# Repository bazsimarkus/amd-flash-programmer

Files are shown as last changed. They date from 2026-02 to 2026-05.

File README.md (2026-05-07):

# amd-flash-programmer
A simple Arduino-based flash memory programmer for AM29F010 and AM29F040B series flash chips.

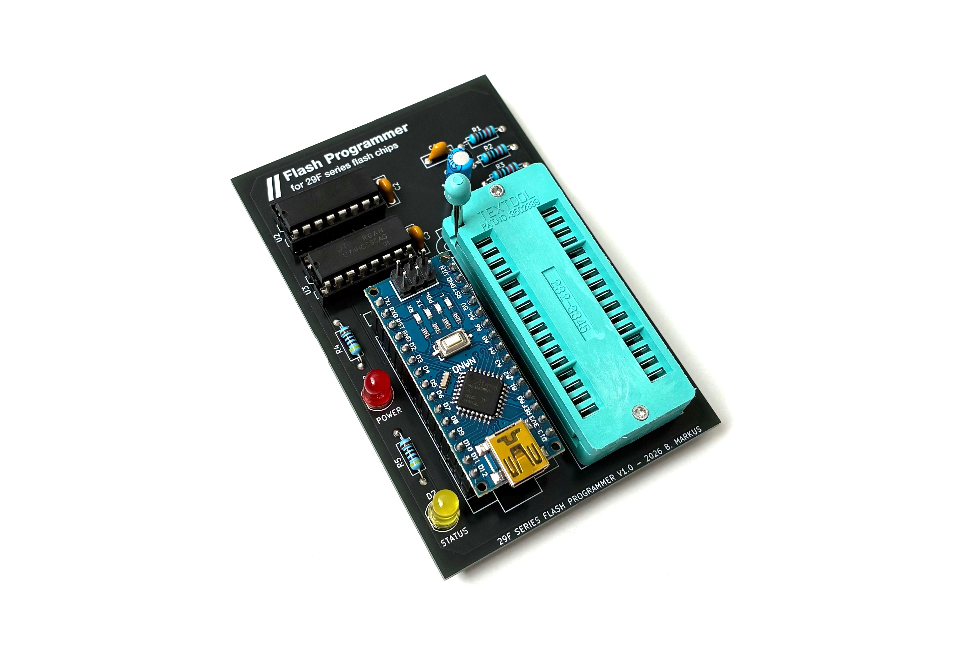
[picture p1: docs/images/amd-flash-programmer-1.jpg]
AMD Flash Programmer Board


---

## Table of Contents

- [Overview](#overview)
- [Features](#features)
- [Hardware](#hardware)
  - [Schematic](#schematic)
  - [How It Works](#how-it-works)
  - [Bill of Materials](#bill-of-materials)
  - [Pin Mapping](#pin-mapping)
  - [Supported Chips](#supported-chips)
  - [PCB](#pcb)
- [Firmware](#firmware)
  - [Architecture](#architecture)
  - [Serial Protocol](#serial-protocol)
  - [Uploading the Firmware](#uploading-the-firmware)
- [Client Software](#client-software)
  - [Installation](#installation)
  - [Usage](#usage)
- [How to Use](#how-to-use)
  - [Connect](#connect)
  - [Read Chip ID](#read-chip-id)
  - [Read Memory](#read-memory)
  - [Erase Chip](#erase-chip)
  - [Write File](#write-file)
  - [Verify](#verify)
- [Performance](#performance)
- [Known Limitations & Future Ideas](#known-limitations--future-ideas)
- [Personal Notes](#personal-notes)
- [Inspirations & Credits](#inspirations--credits)

---

## Overview

I always needed a way to program AM29F040B flash chips without spending money on an expensive universal programmer. My [ATmega32-based MOD tracker player](https://github.com/bazsimarkus/avr-mod-player) uses this chip to store `.mod` tracker files, and to be able to write new music onto the player I decided to design a dedicated programmer board. These chips were also used in Game Boy Color cartridges, among other things, so there is a retro community out there that might find this useful too.

My main inspiration was [TommyPROM](https://github.com/TomNisbet/TommyPROM), but TommyPROM is a general-purpose EEPROM programmer and doesn't directly support the AMD 29F-series flash command sequences. The AM29F010 and AM29F040B use software-controlled erase and programming cycles with specific unlock addresses - you can't just write to them like a parallel EEPROM. So I designed my own board, wrote the Arduino firmware from scratch, and also created a Python GUI client to make the whole process beginner-friendly.

The result is a simple, easy-to-build board that does exactly what I need: read, write, erase, and verify AM29F-series flash chips over USB.

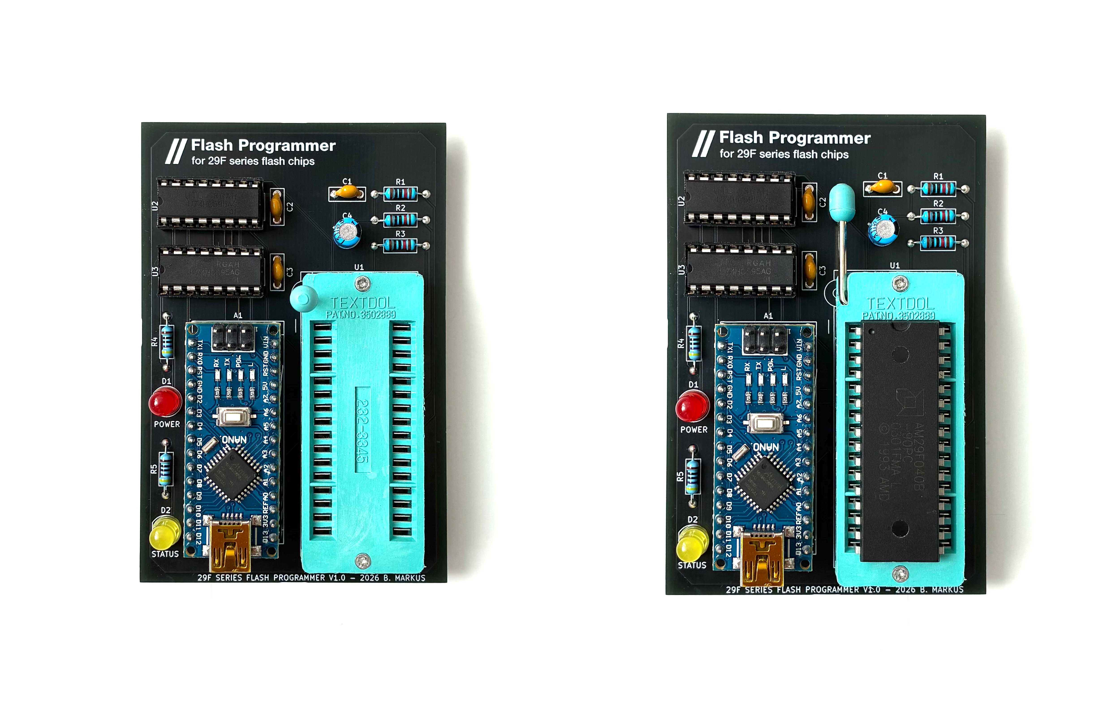
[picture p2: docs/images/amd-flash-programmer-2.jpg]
AMD Flash Programmer Board Double Top View


---

## Features

- **Read** - full chip or custom hex address range, displayed in a live hex viewer
- **Write** - binary files to flash with byte-by-byte handshake protocol
- **Erase** - full chip erase with proper DQ7 data polling
- **Verify** - automatic post-write verification or manual verify against any file
- **Chip ID** - reads manufacturer and device ID via autoselect mode
- **Hex Viewer** - colour-coded hex dump with ASCII column in the GUI
- **Event Log** - timestamped log of all operations, exportable to file
- **COM port auto-detection** - scans and lists available serial ports
- Supports **AM29F010** (128 KB) and **AM29F040B** (512 KB)
- Beginner-friendly - easy to solder, easy to flash, easy to use
- All through-hole components - no SMD soldering required
- Powered directly from USB via the Arduino Nano

---

## Hardware

### Schematic

<p align="center">
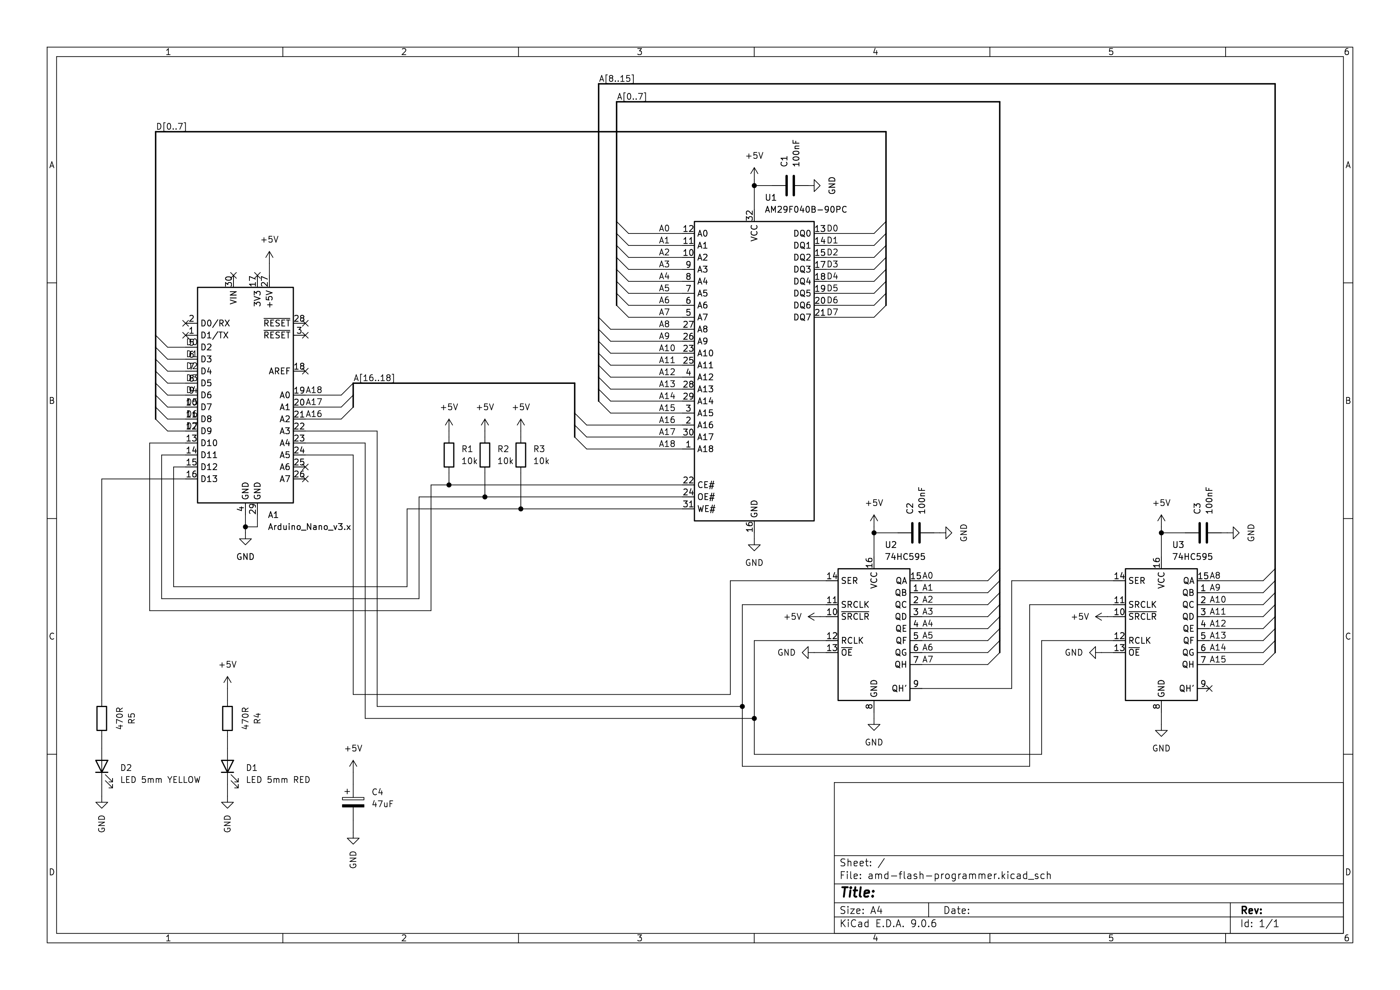
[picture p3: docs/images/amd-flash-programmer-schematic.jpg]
Flash Programmer Schematic
  
</p>

The full KiCad project including schematic, PCB layout, and netlist is available in the `schematic/` folder.

---

### How It Works

The circuit is straightforward. There are only a few building blocks, and each has a clear job.

**Arduino Nano (A1)** - This is the brain of the board. It handles USB serial communication with the PC at 115200 baud, generates the timing for the shift registers, drives the flash chip's control signals (CE#, OE#, WE#), and reads/writes the 8-bit data bus. It is powered directly from the USB cable, and provides 5V to the rest of the circuit from its onboard regulator.

**74HC595 Shift Registers (U2, U3)** - The AM29F040B has 19 address lines (A0-A18), which is far more than what the Arduino Nano has available as spare GPIO. The solution is to use two 74HC595 shift registers daisy-chained together. These are 8-bit serial-in, parallel-out shift registers. The Arduino sends 16 bits of address data serially using just three control lines (serial data on A5, shift clock on A3, and latch clock on A4), and the two shift registers present all 16 bits simultaneously on their parallel outputs. U2 provides address lines A0-A7 (low byte), and its serial overflow output (QH') feeds into U3 which provides A8-A15 (high byte). The remaining three address lines (A16, A17, A18) are driven directly from the Nano's analog pins A0, A1, and A2 - there is no need to shift those since there are only three of them and the Nano has enough free pins.

**Flash Chip Socket (U1)** - A 32-pin ZIF (Zero Insertion Force) Textool socket. ZIF sockets have a lever that opens and closes the contacts, so you can insert and remove DIP chips without bending any pins. This is important because if you are regularly swapping flash chips in and out, a standard friction-fit DIP socket will eventually damage the pins or wear out. The ZIF socket is the most expensive component on the board, but it is worth it.

**Data Bus (D2-D9)** - The flash chip's 8-bit data bus (DQ0-DQ7) connects directly to Arduino Nano pins D2 through D9. These pins are mapped to PORTD bits 2-7 and PORTB bits 0-1 in the firmware. During a read, the Arduino sets these as inputs and reads the parallel data from the flash. During a write, it sets them as outputs and drives the data to be programmed.

**Control Signals (D10, D11, D12)** - Three active-low control signals go from the Arduino to the flash chip:
- **CE#** (Chip Enable) on D10 - must be low for the chip to respond to any bus cycle
- **OE#** (Output Enable) on D11 - drives the chip's data outputs onto the bus during a read
- **WE#** (Write Enable) on D12 - latches data into the chip during a write or command cycle

All three have 10kΩ pull-up resistors (R1, R2, R3) to +5V. This is a safety measure: during Arduino power-up, reset, or bootloader execution, the GPIO pins are momentarily tri-stated (floating). Without the pull-ups, the flash chip might interpret random noise on CE#, OE#, and WE# as valid bus cycles and get confused or, in a worst case, accidentally erase data. The pull-ups ensure all control signals default to their inactive (high) state until the firmware explicitly takes control.

**LEDs (D1, D2)** - A red LED for power indication (always on when USB is connected) and a yellow LED for status (blinks during operations). Each LED has a 470Ω series resistor (R4 for the power LED, R5 for the status LED) to limit the current to a safe value. The status LED is connected to D13, which is the Arduino's built-in LED pin.

**Decoupling Capacitors (C1, C2, C3, C4)** - Three 100nF ceramic capacitors are placed near the power supply pins of U1 (flash chip), U2, and U3 (shift registers). These are standard bypass capacitors that filter out high-frequency noise on the power supply lines. Without them, the rapid switching of the digital logic creates voltage spikes that can cause unreliable operation, especially on the flash chip which has tight timing requirements. C4 is a 47µF electrolytic capacitor providing bulk energy storage for the entire board, smoothing out any supply droop when the flash chip draws current during erase or programming operations.

---

### Bill of Materials

| Reference | Qty | Value / Part | Description |
|---|-----|---|---|
| A1 | 1 | Arduino Nano v3.x | Main microcontroller module (ATmega328P) |
| U1 | 1 | 32-pin ZIF Socket (Textool) | Zero-insertion-force socket for flash chip |
| U2 | 1 | 74HC595 (DIP-16) | 8-bit shift register - address lines A0-A7 |
| U3 | 1 | 74HC595 (DIP-16) | 8-bit shift register - address lines A8-A15 |
| D1 | 1 | LED 5mm RED | Power indicator |
| D2 | 1 | LED 5mm YELLOW | Status indicator (directly controlled via D13) |
| R1, R2 | 2 | 10kΩ | Pull-up resistors for CE# and OE# |
| R3 | 1 | 10kΩ | Pull-up resistor for WE# |
| R4 | 1 | 470Ω | Current limiting resistor for power LED |
| R5 | 1 | 470Ω | Current limiting resistor for status LED |
| C1, C2, C3 | 3 | 100nF ceramic | Decoupling capacitors (one per IC) |
| C4 | 1 | 47µF electrolytic | Bulk power filtering |

All components are through-hole and readily available from any electronics supplier. The total component cost (excluding the Arduino Nano and ZIF socket) is under 2 EUR.

---

### Pin Mapping

The Arduino Nano's pins are allocated as follows:

| Arduino Pin | Port | Function |
|---|---|---|
| D2-D9 | PORTD[2:7], PORTB[0:1] | Flash data bus DQ0-DQ7 |
| D10 | PORTB2 | Flash CE# (active low) |
| D11 | PORTB3 | Flash OE# (active low) |
| D12 | PORTB4 | Flash WE# (active low) |
| D13 | PORTB5 | Status LED |
| A0 | PORTC0 | Flash A18 (directly driven) |
| A1 | PORTC1 | Flash A17 (directly driven) |
| A2 | PORTC2 | Flash A16 (directly driven) |
| A3 | PORTC3 | Shift register SRCLK (clock) |
| A4 | PORTC4 | Shift register RCLK (latch) |
| A5 | PORTC5 | Shift register SER (serial data) |

The two 74HC595 shift registers are daisy-chained: U2 provides A0-A7 and its serial overflow (QH') feeds into U3 which provides A8-A15. This gives 16 address bits via SPI-like shifting, plus 3 bits driven directly, totalling 19 address lines - enough for 512 KB.

---

### Supported Chips

| Chip | Size | Unlock 1 | Unlock 2 | Mfr ID | Dev ID |
|---|---|---|---|---|---|
| AM29F010 | 128 KB (131,072 bytes) | 0x5555 | 0x2AAA | 0x01 | 0x20 |
| AM29F040B | 512 KB (524,288 bytes) | 0x0555 | 0x02AA | 0x01 | 0xA4 |

Note that the two chips use different unlock address sequences - the firmware handles this automatically based on the selected chip type.

---

### PCB

The PCB is revision **v1.0**, designed in KiCad 9.0.6. It is a single-sided through-hole board manufactured with black soldermask and white silkscreen. The board was manufactured by JLCPCB. All components are through-hole for ease of hand assembly - this is a beginner-friendly build that anyone with basic soldering skills can complete in under an hour.

The full KiCad project including schematic, PCB layout, and Gerber files is in the `schematic/` folder.

---

## Firmware

### Architecture

The firmware (`amd-flash-programmer.ino`) is written in C/C++ using the Arduino framework, but with direct port manipulation for speed. It runs at 115200 baud and implements a simple text-based command protocol over serial.

Key design decisions:

- **Direct port manipulation** - the data bus and control signals are manipulated via `PORTB`, `PORTD`, and `PORTC` registers rather than `digitalWrite()`, which would be too slow for the programming timing requirements.
- **Byte-by-byte handshake for writes** - the Arduino Nano has only a 64-byte UART receive buffer. At 115200 baud, bytes arrive at ~11 KB/s, but programming a byte to flash takes up to 200µs. A naive burst approach would overflow the buffer. Instead, the firmware programs one byte, sends a single `'K'` ACK character, and the host waits for that ACK before sending the next byte. This is slower (~0.5 KB/s) but 100% reliable.
- **DQ7 data polling** - both byte programming and chip erase use the AMD-standard DQ7 polling algorithm to detect completion, with DQ5 error checking as a fallback.
- **70-second erase timeout** - the AM29F040B datasheet specifies a maximum chip erase time of ~64 seconds, so the firmware allows up to 70 seconds before declaring a timeout.

---

### Serial Protocol

All commands are ASCII, terminated with `\n`. The Arduino responds with ASCII status lines.

| Command | Description | Response |
|---|---|---|
| `?` | Status query | `STATUS:<chip_name> SIZE:<bytes>` |
| `C<idx>` | Select chip (0=AM29F010, 1=AM29F040B) | `CHIP_OK:<name>` or `CHIP_ERR:...` |
| `I` | Read chip ID (autoselect mode) | `MFR:<hex> DEV:<hex>` |
| `R <start_hex> <end_hex>` | Read address range | `RSTART <count>` + raw bytes + `REND` |
| `E` | Full chip erase | `ERASE_START` → `ERASE_OK` or `ERASE_FAIL` |
| `W <size_dec>` | Write `<size>` bytes | `WREADY` → (byte-by-byte with `K` ACKs) → `WDONE:<n>` |

---

### Uploading the Firmware

1. Open `amd-flash-programmer.ino` in the Arduino IDE
2. Select **Board:** `Arduino Nano`
3. Select **Processor:** `ATmega328P` (or `ATmega328P (Old Bootloader)` depending on your board)
4. Select the correct COM port
5. Click **Upload**

No external libraries are required - the firmware uses only standard AVR headers and the Arduino Serial library.

---

## Client Software

The Python GUI client (`amd-flash-programmer-client.py`) provides a complete graphical interface for interacting with the programmer board.

<p align="center">
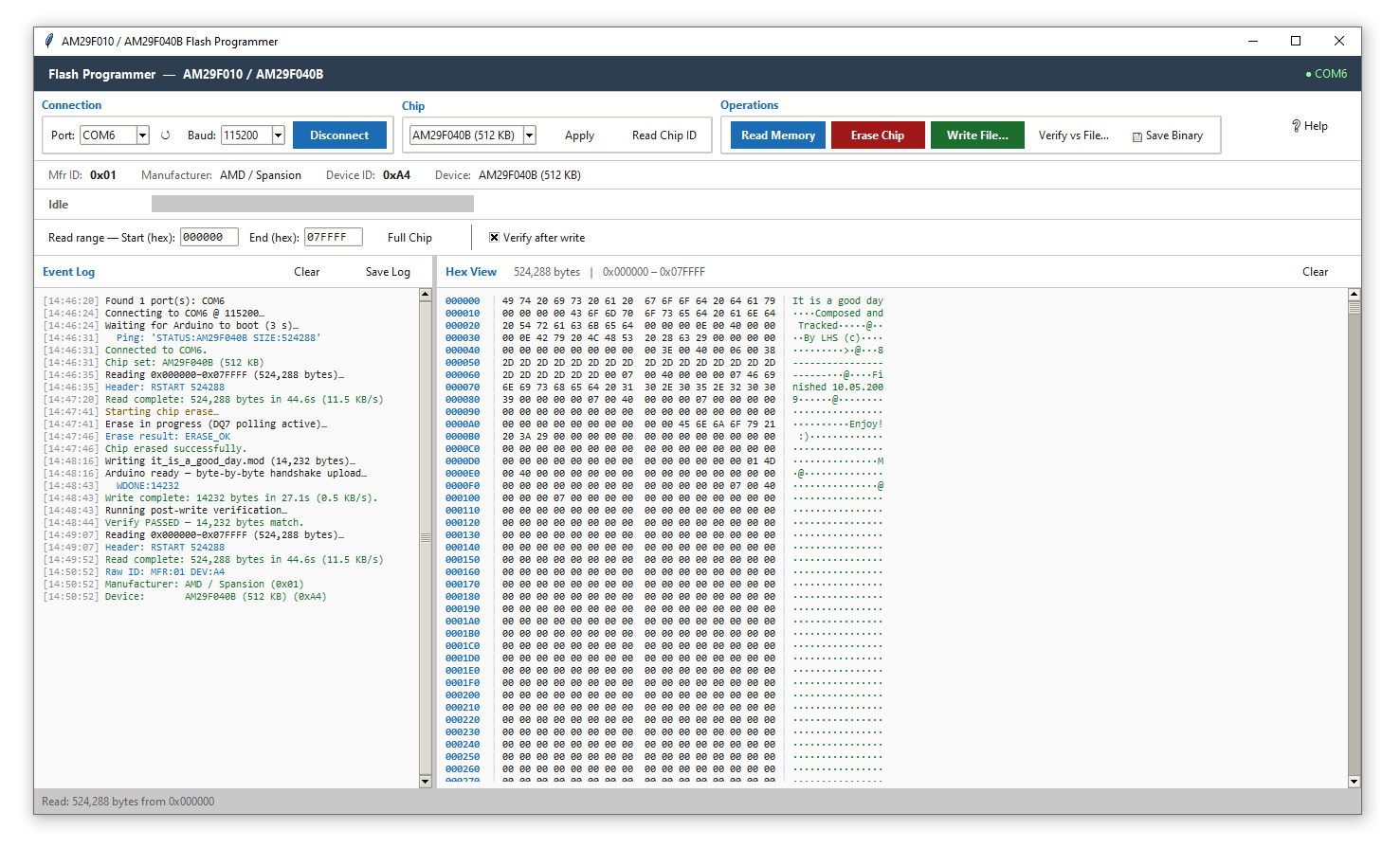
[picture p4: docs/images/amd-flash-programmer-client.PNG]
Flash Programmer Client Software
  
</p>

### Installation

Requires Python 3.x with `pyserial`:

```bash
pip install pyserial
python amd-flash-programmer-client.py
```

The client is built entirely with `tkinter` (included with Python) and `pyserial` - no other dependencies.

---

### Usage

The GUI is split into several sections:

- **Connection panel** - COM port selection, baud rate, connect/disconnect
- **Chip panel** - chip type selection (AM29F010 / AM29F040B), Apply, Read Chip ID
- **Operations panel** - Read Memory, Erase Chip, Write File, Verify vs File, Save Binary
- **Progress bar** - shows real-time progress with speed and ETA
- **Read range** - configurable start/end addresses (hex), Full Chip button
- **Event Log** (left panel) - timestamped log of all events, saveable to file
- **Hex View** (right panel) - colour-coded hex dump with address, hex bytes, and ASCII columns

The client includes a built-in chip database with known manufacturer IDs (AMD/Spansion, Fujitsu, Atmel, ST Micro, SST, Macronix, Winbond, etc.) and will display human-readable names when a chip ID is read.

---

## How to Use

### Connect

1. Insert the flash chip into the ZIF socket - **pin 1 goes to the top** (lever side)
2. Close the ZIF lever to lock the chip in place
3. Connect the Arduino Nano to your computer via USB
4. Launch the Python client
5. Select the correct COM port from the dropdown and click **Connect**
6. The client will reset the Arduino and wait for it to boot (~3 seconds)

### Read Chip ID

Click **Read Chip ID** to enter autoselect mode and read back the manufacturer and device ID bytes. This confirms the chip is correctly inserted and the wiring is working. If you get `FF/FF`, check your connections.

### Read Memory

- Set the start and end addresses in hex, or click **Full Chip** to auto-fill
- Click **Read Memory**
- The contents will be displayed in the Hex View panel
- Click **Save Binary** to export to a `.bin` or `.rom` file

### Erase Chip

Click **Erase Chip** to perform a full chip erase. The operation uses the standard AMD 6-bus-cycle erase sequence and polls DQ7 for completion. Typical erase time is 1-5 seconds, maximum ~64 seconds per datasheet.

> ⚠️ **Important:** Flash chips must be fully erased before writing. You cannot overwrite individual bytes without erasing the entire chip (or at least the sector) first.

### Write File

- Click **Write File...** and select a binary file (`.bin`, `.rom`, `.img`)
- The file will be written byte-by-byte starting at address 0x000000
- Progress is shown in real-time with speed and ETA
- If **Verify after write** is checked, a full readback comparison runs automatically after writing

### Verify

Click **Verify vs File...** to read the chip and compare it byte-for-byte against a reference file. The client will report pass or fail, listing the first 10 mismatches if verification fails.

---

## Performance

| Operation | Speed | Time (full AM29F040B, 512 KB) |
|---|---|---|
| Read | ~11.5 KB/s | ~44.6 seconds |
| Write (byte-by-byte handshake) | ~0.5 KB/s | ~17 minutes |
| Erase | - | 1-5 seconds typical |

The write speed is intentionally slow to ensure reliability. The byte-by-byte ACK handshake prevents UART buffer overflow, which was a problem with burst-mode approaches. For typical use cases (small ROMs, tracker files, cartridge images) the speed is perfectly acceptable.

---

## Known Limitations & Future Ideas

**Write speed** - at ~0.5 KB/s, writing a full 512 KB chip takes about 17 minutes. This is the price of the reliable byte-by-byte handshake protocol. A future improvement could use small block transfers (e.g., 32 bytes at a time) with flow control, but for my use case the current speed is fine.

**No sector erase** - the firmware currently only supports full chip erase. The AM29F040B supports sector-by-sector erase (64 KB sectors), which would be useful for partial updates. This would be straightforward to add but I haven't needed it yet.

**No write offset** - writes always start at address 0x000000. Supporting an arbitrary start address for writes would be a nice addition for partial ROM updates.

**Single-chip wiring** - the board is wired specifically for 32-pin DIP flash chips in the AM29F family. Other pin-compatible chips (like SST39SF040 or similar 5V parallel flash) may work with minor firmware modifications to the unlock sequences, but I haven't tested them.

**No 3.3V support** - the board runs at 5V from the Arduino Nano's USB supply. Some newer flash chips require 3.3V - those are not supported without a level shifter modification.

---

## Personal Notes

This project came about because I needed to program flash chips for my MOD tracker player. I could have bought a TL866 or similar universal programmer, but where is the fun in that? I wanted something I could understand completely, something I could fix if it broke, and something I could share with other hobbyists who might be in the same situation.

The board is deliberately simple - no SMD components, no complex power supply, no FPGA. Just an Arduino Nano, two shift registers, a ZIF socket, and some passives. If you can solder a through-hole kit, you can build this. The Python client is similarly straightforward - one file, one dependency (`pyserial`), and it runs on Windows, Linux, and macOS.

I spent more time debugging the write protocol than anything else. The original approach was to stream bytes at full serial speed and let the Arduino buffer them, but the 64-byte UART buffer combined with variable programming times (0xFF bytes are instant, non-FF bytes take up to 200µs) meant that overflow was inevitable for non-trivial files. The byte-by-byte handshake is slower but it has never failed on me.

The DQ7 polling implementation also took some careful reading of the datasheet. The AMD flash programming algorithm is well-documented but subtle - you need to check DQ5 (timeout flag) as well as DQ7 (data polling), and you need to do a final read after DQ5 triggers to avoid false failures. Getting this right meant the difference between a programmer that works on the bench and one that works reliably every time.

---

## Inspirations & Credits

- **Tom Nisbet** - [TommyPROM](https://github.com/TomNisbet/TommyPROM)
  The project that showed me an Arduino-based EEPROM/flash programmer was viable and well within reach.

- **AMD / Spansion** - AM29F040B Datasheet
  The reference for all programming sequences, timing, and polling algorithms.

- **KiCad** - [kicad.org](https://www.kicad.org/)
  Schematic and PCB design.

- **Python** / **pyserial** / **tkinter**
  The client software stack.

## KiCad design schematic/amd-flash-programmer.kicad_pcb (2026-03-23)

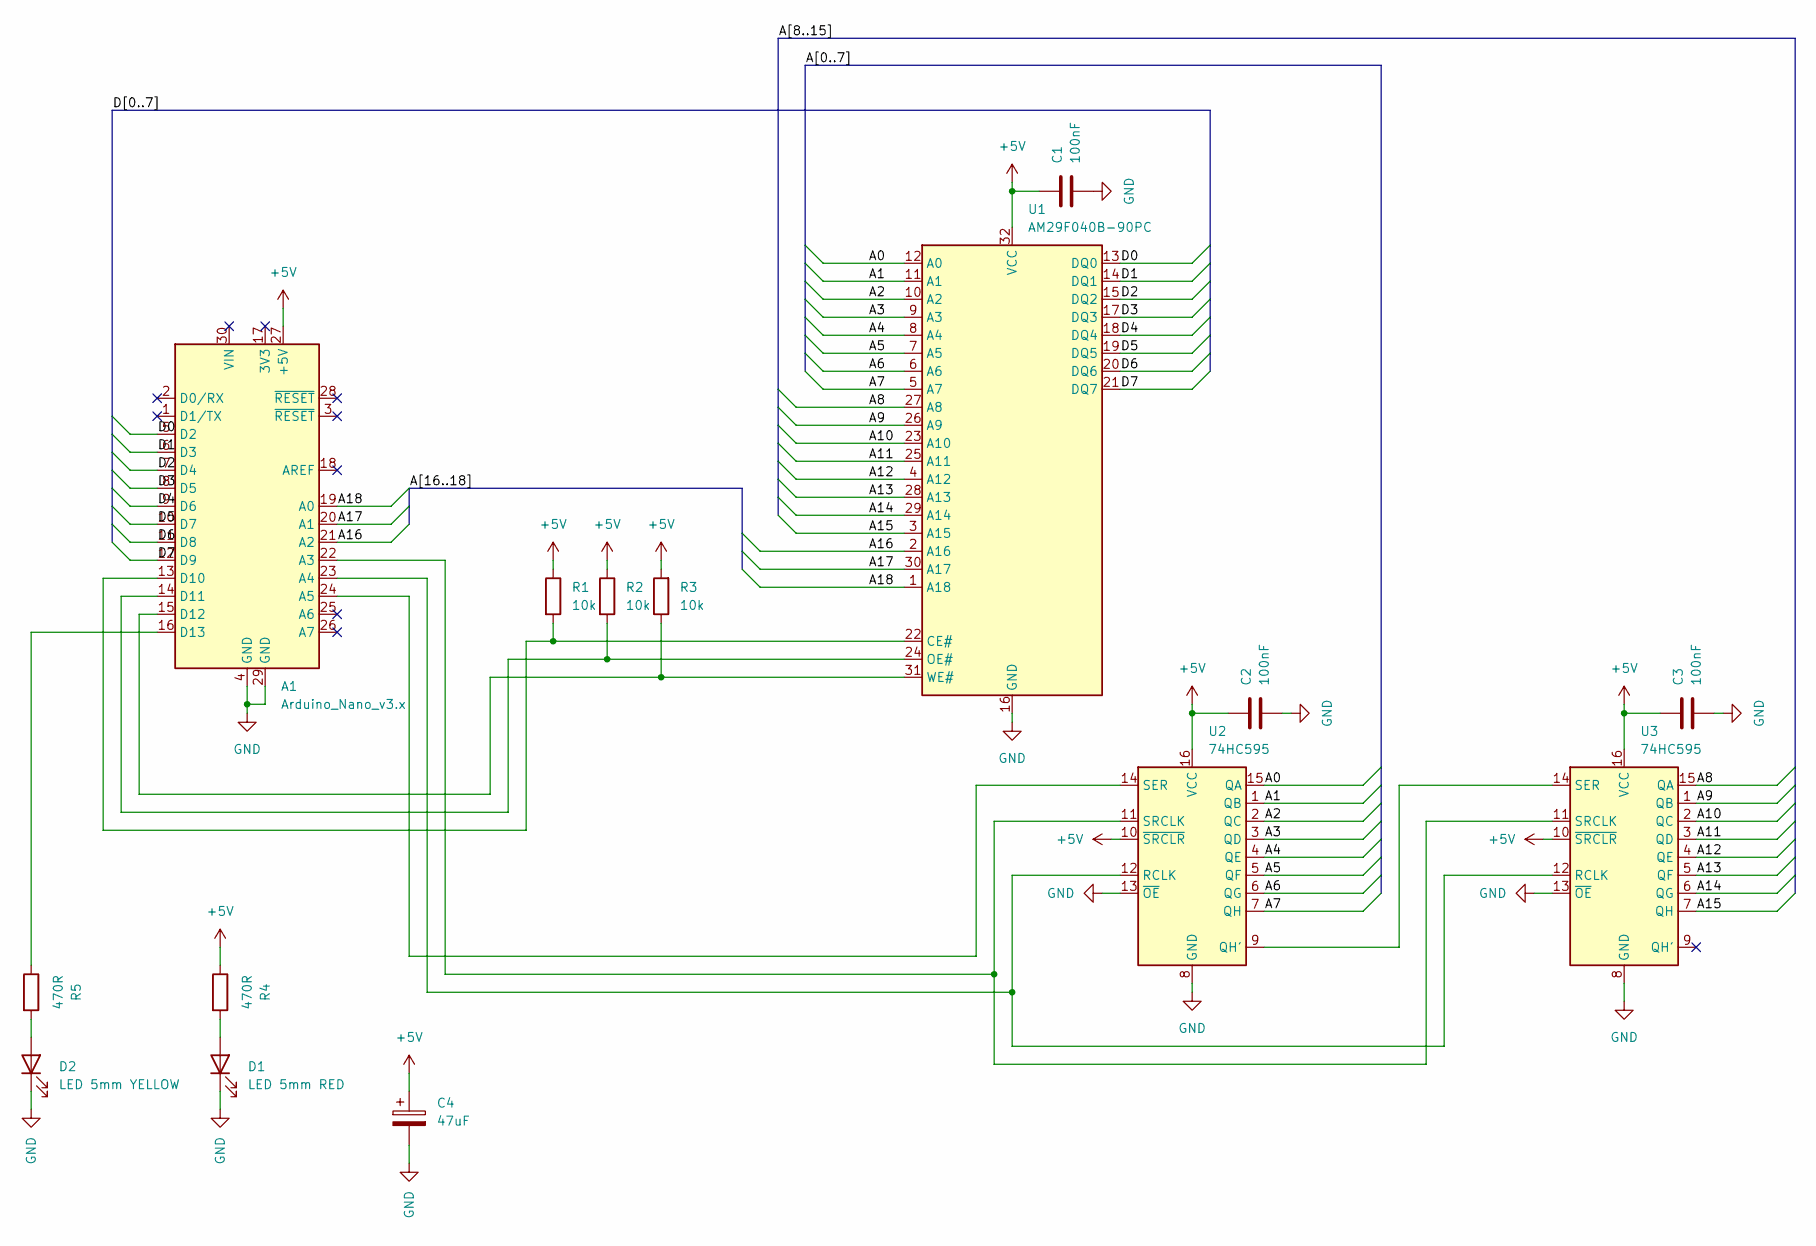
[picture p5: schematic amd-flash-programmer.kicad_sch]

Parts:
A1: Arduino_Nano_v3.x; Arduino_Nano
C1, C2, C3: 100nF; C_100nF_L7.0mm_W2.5mm_P5.00mm
C4: 47uF; CP_Radial_D5.0mm_P2.00mm
D1: LED 5mm RED; LED_D5.0mm_RED
D2: LED 5mm YELLOW; LED_D5.0mm_YELLOW
R1, R2, R3: 10k; R_10k_Axial_DIN0207
R4, R5: 470R; R_470_Axial_DIN0207
U1: AM29F040B-90PC; DIP_Socket-32_W11.9mm_W12.7mm_W15.24mm_W17.78mm_W18.5mm_3M_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
U2, U3: 74HC595; DIP-16_W7.62mm

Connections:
+5V: A1.27 (+5V), C1.1, C2.1, C3.1, C4.1, R1.1, R2.1, R3.2, R4.1, U1.32 (VCC), U2.10 (~SRCLR), U2.16 (VCC), U3.10 (~SRCLR), U3.16 (VCC)
/A0: U1.12 (A0), U2.15 (QA)
/A1: U1.11 (A1), U2.1 (QB)
/A2: U1.10 (A2), U2.2 (QC)
/A3: U1.9 (A3), U2.3 (QD)
/A4: U1.8 (A4), U2.4 (QE)
/A5: U1.7 (A5), U2.5 (QF)
/A6: U1.6 (A6), U2.6 (QG)
/A7: U1.5 (A7), U2.7 (QH)
/A8: U1.27 (A8), U3.15 (QA)
/A9: U1.26 (A9), U3.1 (QB)
/A10: U1.23 (A10), U3.2 (QC)
/A11: U1.25 (A11), U3.3 (QD)
/A12: U1.4 (A12), U3.4 (QE)
/A13: U1.28 (A13), U3.5 (QF)
/A14: U1.29 (A14), U3.6 (QG)
/A15: U1.3 (A15), U3.7 (QH)
/A16: A1.21 (A2), U1.2 (A16)
/A17: A1.20 (A1), U1.30 (A17)
/A18: A1.19 (A0), U1.1 (A18)
/D0: A1.5 (D2), U1.13 (DQ0)
/D1: A1.6 (D3), U1.14 (DQ1)
/D2: A1.7 (D4), U1.15 (DQ2)
/D3: A1.8 (D5), U1.17 (DQ3)
/D4: A1.9 (D6), U1.18 (DQ4)
/D5: A1.10 (D7), U1.19 (DQ5)
/D6: A1.11 (D8), U1.20 (DQ6)
/D7: A1.12 (D9), U1.21 (DQ7)
GND: A1.4 (GND), A1.29 (GND), C1.2, C2.2, C3.2, C4.2, D1.1 (K), D2.1 (K), U1.16 (GND), U2.8 (GND), U2.13 (~OE), U3.8 (GND), U3.13 (~OE)
unnamed: A1.22 (A3), U2.11 (SRCLK), U3.11 (SRCLK)
unnamed: A1.23 (A4), U2.12 (RCLK), U3.12 (RCLK)
unnamed: A1.24 (A5), U2.14 (SER)
unnamed: A1.13 (D10), R1.2, U1.22 (CE#)
unnamed: A1.14 (D11), R2.2, U1.24 (OE#)
unnamed: A1.15 (D12), R3.1, U1.31 (WE#)
unnamed: A1.16 (D13), R5.1
unnamed: D1.2 (A), R4.2
unnamed: D2.2 (A), R5.2
unnamed: U2.9 (QH'), U3.14 (SER)

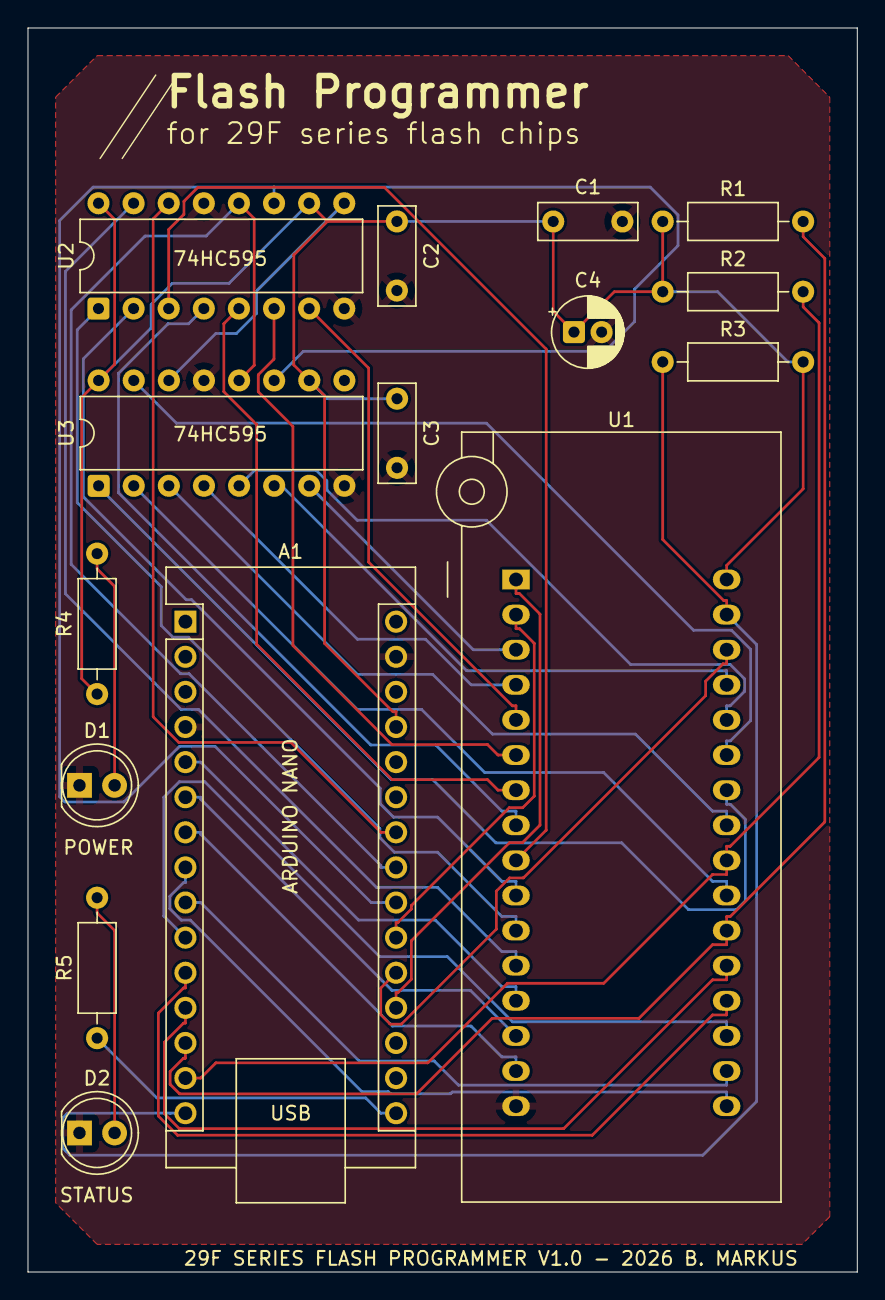
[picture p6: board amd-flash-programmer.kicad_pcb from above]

Board: 2 copper layers, 60.0 x 90.0 mm, 15 parts (0 on the bottom side), 39 nets.

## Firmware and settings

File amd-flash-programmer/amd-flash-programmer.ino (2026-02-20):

/* =============================================================================
   AMD FLASH PROGRAMMER - Universal (AM29F010 / AM29F040B)
   
   Author: Balazs Markus
   Rewritten & Extended for AM29F040B support, chip selection,
   robust erase polling, and improved serial protocol.

   Wiring (Arduino Nano):
     Shift Registers (74HC595 x2, daisy-chained):
       A5 -> SR1 DS (Serial Data)
       A4 -> Both RCLK (Latch)
       A3 -> Both SRCLK (Shift Clock)
     High Address Lines:
       A2 -> A16, A1 -> A17, A0 -> A18
     Data Bus:
       D2-D9 -> Flash DQ0-DQ7
     Control:
       D10 -> CE#, D11 -> OE#, D12 -> WE#

   Serial Protocol (115200 baud):
     All commands are ASCII. Arduino always terminates responses with '\n'.

     'C' <chip_id>\n      - Select chip: '0'=AM29F010, '1'=AM29F040B
     'I'\n                - Get chip ID: returns "MFR:<hex> DEV:<hex>\n"
     'R' <start_hex> <end_hex>\n - Read range, returns binary with SIZE\n prefix
                                   Actually returns: "RSTART\n" then bytes then "REND\n"
     'E'\n                - Chip erase. Returns "ERASE_START\n", polls DQ7,
                            then returns "ERASE_OK\n" or "ERASE_FAIL\n"
     'W' <size_dec>\n     - Write: Arduino replies "WREADY\n", then accepts
                            <size> raw bytes, replies "WDONE\n" or "WERR:<addr>\n"
     'V' <start_hex> <end_hex>\n - Verify: same format as read (for post-write check)
     
   ============================================================================= */

#include <avr/io.h>
#include <util/delay.h>

// ---- Chip definitions -------------------------------------------------------
// Each chip has its own unlock address pair and size
struct ChipDef {
  uint32_t unlock1;   // First unlock address (e.g. 0x5555 or 0x555)
  uint32_t unlock2;   // Second unlock address (e.g. 0x2AAA or 0x2AA)
  uint32_t flash_size;// Total flash size in bytes
  const char *name;
};

const ChipDef CHIPS[] = {
  { 0x5555, 0x2AAA, 131072UL,  "AM29F010"  },  // chip index 0
  { 0x555,  0x2AA,  524288UL,  "AM29F040B" },  // chip index 1 (default)
};

#define DEFAULT_CHIP_IDX 1  // AM29F040B
#define NUM_CHIPS 2

int  g_chip_idx = DEFAULT_CHIP_IDX;
uint32_t g_ul1;    // unlock address 1 (cached)
uint32_t g_ul2;    // unlock address 2 (cached)
uint32_t g_flash_size;

// ---- Erase timeout ----------------------------------------------------------
// AM29F040B chip erase max time is ~64s per datasheet, we use 70s
#define ERASE_TIMEOUT_MS 70000UL

// ---- Pin assignments (do not change without updating port manipulation) ------
// D2-D7 = PORTD bits 2-7
// D8-D9 = PORTB bits 0-1
// D10=PORTB2(CE#), D11=PORTB3(OE#), D12=PORTB4(WE#)
// A3=PORTC3(SRCLK), A4=PORTC4(RCLK), A5=PORTC5(SER)
// A0=PORTC0(A18),  A1=PORTC1(A17),   A2=PORTC2(A16)

// =============================================================================
// LOW LEVEL PIN CONTROL
// =============================================================================

void set_data_input() {
  DDRD &= 0x03;   // D2-D7 as input (keep D0,D1 for Serial)
  DDRB &= ~0x03;  // D8-D9 as input
  // Disable pull-ups
  PORTD &= 0x03;
  PORTB &= ~0x03;
}

void set_data_output() {
  DDRD |= 0xFC;   // D2-D7 as output
  DDRB |= 0x03;   // D8-D9 as output
}

void flash_ctrl_deselect() {
  // CE#=HIGH, WE#=HIGH, OE#=HIGH  (all inactive)
  PORTB |=  (1<<2)|(1<<3)|(1<<4);
}

void flash_ctrl_read() {
  // OE#=LOW first, then CE#=LOW
  PORTB &= ~(1<<3);  // OE# low
  _delay_us(1);
  PORTB &= ~(1<<2);  // CE# low
  _delay_us(1);
}

void flash_ctrl_write_pulse() {
  // CE# already low. Pulse WE#.
  PORTB &= ~(1<<2);  // CE# low
  _delay_us(1);
  PORTB &= ~(1<<4);  // WE# low
  _delay_us(1);
  PORTB |=  (1<<4);  // WE# high
  _delay_us(1);
}

// =============================================================================
// ADDRESS SETTING
// =============================================================================

void flash_set_high_addr(uint16_t addr) {
  // A16 = PORTC2, A17 = PORTC1, A18 = PORTC0
  if (addr & 0x01) PORTC |=  _BV(PORTC2); else PORTC &= ~_BV(PORTC2);
  if (addr & 0x02) PORTC |=  _BV(PORTC1); else PORTC &= ~_BV(PORTC1);
  if (addr & 0x04) PORTC |=  _BV(PORTC0); else PORTC &= ~_BV(PORTC0);
}

void flash_shift_addr16(uint16_t data) {
  // Send 16-bit address to shift registers (MSB first into SR2, LSB into SR1)
  // SR2 = A15..A8 (high byte), SR1 = A7..A0 (low byte)
  // We shift MSB of high byte first
  uint8_t hi = (data >> 8) & 0xFF;
  uint8_t lo = (data)      & 0xFF;

  PORTC &= ~_BV(PORTC4);  // Latch LOW

  // Shift high byte (A15..A8) first — ends up in SR2
  for (int i = 7; i >= 0; i--) {
    PORTC &= ~_BV(PORTC3); // SRCLK LOW
    if (hi & (1 << i)) PORTC |= _BV(PORTC5);
    else                PORTC &= ~_BV(PORTC5);
    PORTC |= _BV(PORTC3);  // SRCLK HIGH (shift in)
  }

  // Shift low byte (A7..A0) — ends up in SR1
  for (int i = 7; i >= 0; i--) {
    PORTC &= ~_BV(PORTC3);
    if (lo & (1 << i)) PORTC |= _BV(PORTC5);
    else                PORTC &= ~_BV(PORTC5);
    PORTC |= _BV(PORTC3);
  }

  PORTC |= _BV(PORTC4);  // Latch HIGH — outputs update
}

void flash_set_addr(uint32_t addr) {
  flash_shift_addr16((uint16_t)(addr & 0xFFFF));
  flash_set_high_addr((uint16_t)((addr >> 16) & 0x07));
}

// =============================================================================
// DATA BUS I/O
// =============================================================================

void flash_write_data(uint8_t data) {
  // D2-D7 = data bits 0-5, D8 = bit 6, D9 = bit 7
  // Map: data bit N -> Arduino pin (N+2), except bits 6,7 -> pins 8,9
  uint8_t portd_mask = (data << 2) & 0xFC;
  uint8_t portb_mask = (data >> 6) & 0x03;

  PORTD = (PORTD & 0x03) | portd_mask;
  PORTB = (PORTB & 0xFC) | portb_mask;
}

uint8_t flash_read_data() {
  uint8_t portd_val = (PIND >> 2) & 0x3F;
  uint8_t portb_val = (PINB & 0x03) << 6;
  return portd_val | portb_val;
}

// =============================================================================
// COMMAND SEQUENCING
// =============================================================================

void load_chip_params() {
  g_ul1        = CHIPS[g_chip_idx].unlock1;
  g_ul2        = CHIPS[g_chip_idx].unlock2;
  g_flash_size = CHIPS[g_chip_idx].flash_size;
}

// Send a command bus cycle (address + data write)
void flash_cmd(uint32_t addr, uint8_t data) {
  flash_set_addr(addr);
  _delay_us(1);
  set_data_output();
  flash_write_data(data);
  flash_ctrl_write_pulse();
  flash_ctrl_deselect();
}

// Standard unlock sequence
void flash_unlock() {
  flash_cmd(g_ul1, 0xAA);
  flash_cmd(g_ul2, 0x55);
}

void flash_reset() {
  flash_cmd(g_ul1, 0xAA);
  flash_cmd(g_ul2, 0x55);
  flash_cmd(g_ul1, 0xF0);
  _delay_ms(10);
}

// =============================================================================
// POLLING - DQ7 Data Polling (proper implementation)
// =============================================================================

// Returns true = operation complete, false = timeout
bool wait_for_dq7(uint32_t addr, uint8_t expected_data, uint32_t timeout_ms) {
  uint8_t expected_dq7 = expected_data & 0x80;
  uint32_t start = millis();
  
  set_data_input();
  flash_set_addr(addr);
  PORTB &= ~(1<<2);  // CE# low
  PORTB &= ~(1<<3);  // OE# low

  while (millis() - start < timeout_ms) {
    uint8_t val = flash_read_data();
    if ((val & 0x80) == expected_dq7) {
      // DQ7 matches — but also check DQ5 (error bit) isn't set after match
      PORTB |= (1<<2)|(1<<3);  // deselect
      return true;
    }
    // Check DQ5 (error flag)
    if (val & 0x20) {
      // DQ5 set — read once more to confirm
      uint8_t val2 = flash_read_data();
      PORTB |= (1<<2)|(1<<3);
      if ((val2 & 0x80) == expected_dq7) return true;
      return false;  // Confirmed error
    }
  }
  PORTB |= (1<<2)|(1<<3);
  return false;  // Timeout
}

// Erase poll: wait for DQ7=1 at address 0, with long timeout
bool wait_for_erase(uint32_t timeout_ms) {
  uint32_t start = millis();
  
  set_data_input();
  flash_set_addr(0x00);
  PORTB &= ~(1<<2);
  PORTB &= ~(1<<3);
  
  while (millis() - start < timeout_ms) {
    uint8_t val = flash_read_data();
    if (val & 0x80) {
      // DQ7=1 means erase complete
      // Also verify DQ3 toggling has stopped and read again
      PORTB |= (1<<2)|(1<<3);
      // Read back to confirm
      flash_set_addr(0x00);
      PORTB &= ~(1<<2);
      PORTB &= ~(1<<3);
      _delay_us(2);
      uint8_t confirm = flash_read_data();
      PORTB |= (1<<2)|(1<<3);
      return (confirm & 0x80) != 0;
    }
    // DQ5=1 while DQ7=0 => error
    if ((val & 0x20) && !(val & 0x80)) {
      uint8_t val2 = flash_read_data();
      PORTB |= (1<<2)|(1<<3);
      if (val2 & 0x80) return true;
      return false;
    }
  }
  PORTB |= (1<<2)|(1<<3);
  return false;
}

// =============================================================================
// AUTOSELECT: Read Manufacturer & Device ID
// =============================================================================

void flash_read_ids(uint8_t *mfr_id, uint8_t *dev_id) {
  flash_ctrl_deselect();
  _delay_ms(5);
  
  // Enter autoselect
  flash_unlock();
  flash_cmd(g_ul1, 0x90);
  _delay_ms(2);
  
  // Read Manufacturer ID (addr 0x00)
  set_data_input();
  flash_set_addr(0x00);
  flash_ctrl_read();
  _delay_us(2);
  *mfr_id = flash_read_data();
  flash_ctrl_deselect();
  
  // Read Device ID (addr 0x01)
  flash_set_addr(0x01);
  flash_ctrl_read();
  _delay_us(2);
  *dev_id = flash_read_data();
  flash_ctrl_deselect();
  
  // Exit autoselect (software reset)
  set_data_output();
  flash_cmd(0x00, 0xF0);
  _delay_ms(5);
}

// =============================================================================
// READ MEMORY
// =============================================================================

void flash_read_range(uint32_t start_addr, uint32_t end_addr) {
  uint32_t count = end_addr - start_addr + 1;
  
  Serial.print(F("RSTART "));
  Serial.println(count);  // Tell host how many bytes to expect
  
  set_data_input();
  
  // Use a 64-byte block buffer for speed
  uint8_t block[64];
  uint32_t i = start_addr;
  
  while (i <= end_addr) {
    uint8_t chunk = (uint8_t)min((uint32_t)64, end_addr - i + 1);
    for (uint8_t b = 0; b < chunk; b++) {
      flash_set_addr(i + b);
      flash_ctrl_read();
      _delay_us(1);
      block[b] = flash_read_data();
      flash_ctrl_deselect();
    }
    Serial.write(block, chunk);
    i += chunk;
  }
  
  Serial.println(F("REND"));
}

// =============================================================================
// ERASE
// =============================================================================

void flash_erase_chip() {
  Serial.println(F("ERASE_START"));
  
  flash_ctrl_deselect();
  set_data_output();
  _delay_ms(10);
  
  // Chip erase sequence
  flash_unlock();
  flash_cmd(g_ul1, 0x80);
  flash_unlock();
  flash_cmd(g_ul1, 0x10);
  
  // Now poll DQ7 — must become 1 when done
  bool ok = wait_for_erase(ERASE_TIMEOUT_MS);
  
  set_data_output();
  flash_reset();
  flash_ctrl_deselect();
  
  if (ok) {
    Serial.println(F("ERASE_OK"));
  } else {
    Serial.println(F("ERASE_FAIL"));
  }
}

// =============================================================================
// PROGRAM
// =============================================================================

// Program a single byte. Returns true on success.
// NOTE: Does NOT skip 0xFF — caller must write all bytes faithfully.
// Skipping 0xFF is an optimisation only valid if you know the chip was freshly
// erased; for general use we must write every byte the host sends us.
bool flash_program_byte(uint32_t addr, uint8_t data) {
  // 0xFF is the erased state — writing it is a no-op but still valid.
  // We skip it purely for speed; the chip ignores such writes anyway.
  // IMPORTANT: We do NOT skip 0x00 or any other value.
  if (data == 0xFF) return true;

  set_data_output();
  flash_unlock();
  flash_cmd(g_ul1, 0xA0);   // Byte-program command

  // Write data to target address
  flash_set_addr(addr);
  flash_write_data(data);
  flash_ctrl_write_pulse();
  flash_ctrl_deselect();

  // Poll DQ7 for completion (up to 500 ms — datasheet max for byte program is ~9 µs
  // typical, 200 µs max for AM29F040B, but we're generous to handle slow chips).
  return wait_for_dq7(addr, data, 500);
}

// =============================================================================
// WRITE OPERATION — byte-by-byte handshaked protocol
//
// WHY: The Arduino Nano has a 64-byte hardware serial receive buffer.
// Programming a non-0xFF byte takes ~6 µs typical, up to 200 µs max.
// At 115200 baud that's ~11 bytes arriving per millisecond.
// If we buffer 64 bytes and then program them, new bytes arrive during
// programming and overflow the UART buffer — causing WERR_TIMEOUT.
//
// FIX: Strict one-byte-at-a-time handshake.
//   1. Host sends one byte.
//   2. Arduino programs it (takes ≤ 200 µs), then sends one-byte ACK 'K'.
//   3. Host waits for 'K' before sending the next byte.
//
// This is slower than burst mode (throughput ~5 KB/s instead of 11 KB/s)
// but 100% reliable because the UART buffer is never full.
//
// For a 14 KB file this means ~3 seconds — perfectly acceptable.
// For a full 512 KB chip it would take ~100 seconds — also fine.
// =============================================================================

void flash_write_from_serial(uint32_t size) {
  Serial.println(F("WREADY"));  // Tell host we're ready for byte 0

  set_data_output();

  uint32_t addr     = 0;
  uint32_t received = 0;

  while (received < size) {
    // Wait for exactly one byte with a generous timeout (2 s).
    // Host must send the next byte only after receiving our 'K' ACK,
    // so 2 s is more than enough even on slow machines.
    uint32_t wait_start = millis();
    while (!Serial.available()) {
      if (millis() - wait_start > 2000) {
        // Host stopped sending — abort
        Serial.print(F("WERR_TIMEOUT:"));
        Serial.println(received);
        return;
      }
    }

    uint8_t b = (uint8_t)Serial.read();

    if (!flash_program_byte(addr, b)) {
      // Programming failure at this address
      set_data_output();
      flash_ctrl_deselect();
      Serial.print(F("WERR:"));
      Serial.println(addr);
      return;
    }

    addr++;
    received++;

    // ACK: send a single 'K' byte so the host knows it can send the next byte.
    // We use Serial.write (not println) to keep it compact and fast.
    Serial.write('K');
  }

  set_data_output();
  flash_ctrl_deselect();

  // All bytes written successfully
  Serial.print(F("WDONE:"));
  Serial.println(received);
}

// =============================================================================
// SETUP & LOOP
// =============================================================================

void setup() {
  Serial.begin(115200);
  
  // Shift register pins
  pinMode(A5, OUTPUT);
  pinMode(A4, OUTPUT);
  pinMode(A3, OUTPUT);
  
  // High address pins
  pinMode(A2, OUTPUT);
  pinMode(A1, OUTPUT);
  pinMode(A0, OUTPUT);
  
  // Control pins: CE#, OE#, WE#
  // Default HIGH (deselected)
  PORTB |= (1<<2)|(1<<3)|(1<<4);
  DDRB  |= (1<<2)|(1<<3)|(1<<4);
  
  // Data pins default as outputs, low
  set_data_output();
  
  // Init latch/clock lines
  PORTC &= ~(_BV(PORTC3)|_BV(PORTC4)|_BV(PORTC5));
  
  // Init high address bits to 0
  PORTC &= ~(_BV(PORTC0)|_BV(PORTC1)|_BV(PORTC2));
  
  _delay_ms(50);
  
  // Load default chip
  load_chip_params();
  flash_ctrl_deselect();
  
  Serial.println(F("READY"));
}

void loop() {
  if (!Serial.available()) return;
  
  // Read command line
  char cmd_line[32];
  int len = Serial.readBytesUntil('\n', cmd_line, sizeof(cmd_line) - 1);
  cmd_line[len] = '\0';
  
  // Trim trailing CR
  if (len > 0 && cmd_line[len-1] == '\r') {
    cmd_line[--len] = '\0';
  }
  
  if (len == 0) return;
  
  char cmd = cmd_line[0];
  
  switch (cmd) {
    
    case 'C': {
      // Select chip: 'C0' or 'C1'
      if (len >= 2) {
        int idx = cmd_line[1] - '0';
        if (idx >= 0 && idx < NUM_CHIPS) {
          g_chip_idx = idx;
          load_chip_params();
          Serial.print(F("CHIP_OK:"));
          Serial.println(CHIPS[g_chip_idx].name);
        } else {
          Serial.println(F("CHIP_ERR:Invalid index"));
        }
      }
      break;
    }
    
    case 'I': {
      // Read manufacturer and device ID
      uint8_t mfr = 0, dev = 0;
      flash_read_ids(&mfr, &dev);
      Serial.print(F("MFR:"));
      if (mfr < 0x10) Serial.print('0');
      Serial.print(mfr, HEX);
      Serial.print(F(" DEV:"));
      if (dev < 0x10) Serial.print('0');
      Serial.println(dev, HEX);
      break;
    }
    
    case 'R': {
      // Read range: 'R <start_hex> <end_hex>'
      // Parse parameters
      uint32_t start_addr = 0;
      uint32_t end_addr   = g_flash_size - 1;
      
      if (len > 2) {
        char *p = cmd_line + 2;
        start_addr = strtoul(p, &p, 16);
        while (*p == ' ') p++;
        if (*p) end_addr = strtoul(p, NULL, 16);
      }
      
      // Clamp to chip size
      if (end_addr >= g_flash_size) end_addr = g_flash_size - 1;
      if (start_addr > end_addr) {
        Serial.println(F("READ_ERR:Invalid range"));
        break;
      }
      
      flash_read_range(start_addr, end_addr);
      break;
    }
    
    case 'E': {
      // Chip erase
      flash_erase_chip();
      break;
    }
    
    case 'W': {
      // Write: 'W <size_dec>'
      if (len > 2) {
        uint32_t size = strtoul(cmd_line + 2, NULL, 10);
        if (size == 0 || size > g_flash_size) {
          Serial.println(F("WERR_SIZE:Invalid size"));
          break;
        }
        flash_write_from_serial(size);
      } else {
        Serial.println(F("WERR_SIZE:No size given"));
      }
      break;
    }
    
    case '?': {
      // Status / chip info
      Serial.print(F("STATUS:"));
      Serial.print(CHIPS[g_chip_idx].name);
      Serial.print(F(" SIZE:"));
      Serial.println(g_flash_size);
      break;
    }
    
    default:
      Serial.print(F("ERR:Unknown command "));
      Serial.println(cmd);
      break;
  }
}

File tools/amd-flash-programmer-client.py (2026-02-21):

#!/usr/bin/env python3
"""
AM29F010 / AM29F040B Flash Programmer GUI
Compatible with FLASH_PROGRAMMER.ino (Arduino Nano)
Requires: pip install pyserial
"""

import tkinter as tk
from tkinter import ttk, filedialog, messagebox
import serial
import serial.tools.list_ports
import threading
import time
import os
import re

# ─────────────────────────────────────────────────────────────────────────────
# CHIP DATABASE  (indices must match Arduino sketch)
# ─────────────────────────────────────────────────────────────────────────────
CHIP_DB = {
    "AM29F040B (512 KB)": {"index": 1, "size": 524_288,  "mfr_id": "01", "dev_id": "A4"},
    "AM29F010  (128 KB)": {"index": 0, "size": 131_072,  "mfr_id": "01", "dev_id": "20"},
}
DEFAULT_CHIP = "AM29F040B (512 KB)"

MFR_NAMES = {
    "01": "AMD / Spansion", "04": "Fujitsu",    "1F": "Atmel",
    "20": "ST Micro",       "37": "AMIC",        "89": "Intel",
    "AD": "Hynix",          "BF": "SST",         "C2": "Macronix",
    "DA": "Winbond",
}
DEV_NAMES = {
    "20": "AM29F010 (128 KB)",
    "A4": "AM29F040B (512 KB)",
    "5B": "AM29F040  (512 KB)",
}

BAUD_RATES = ["115200", "57600", "38400", "19200", "9600"]

# ─────────────────────────────────────────────────────────────────────────────
# SERIAL WORKER
# ─────────────────────────────────────────────────────────────────────────────
class SerialWorker:
    def __init__(self, port: serial.Serial):
        self.port = port

    def flush(self):
        self.port.reset_input_buffer()
        self.port.reset_output_buffer()

    def send_cmd(self, cmd: str):
        self.port.write((cmd + "\n").encode())

    def read_line(self, timeout=5.0) -> str:
        self.port.timeout = timeout
        return self.port.readline().decode(errors="replace").strip()

    def read_exact(self, n: int, progress_cb=None, timeout=120.0) -> bytes:
        data = bytearray()
        deadline = time.time() + timeout
        while len(data) < n:
            if time.time() > deadline:
                raise TimeoutError(f"Timed out — got {len(data)}/{n} bytes")
            avail = self.port.in_waiting
            if avail:
                chunk = self.port.read(min(avail, n - len(data)))
                data.extend(chunk)
                if progress_cb:
                    progress_cb(len(data), n)
            else:
                time.sleep(0.005)
        return bytes(data)


# ─────────────────────────────────────────────────────────────────────────────
# LIGHT PALETTE
# ─────────────────────────────────────────────────────────────────────────────
C = {
    "bg":        "#F0F0F0",
    "panel":     "#FFFFFF",
    "border":    "#C8C8C8",
    "hdr_bg":    "#2C3E50",
    "hdr_fg":    "#FFFFFF",
    "accent":    "#1A6DB5",
    "ok":        "#1B6E2E",
    "warn":      "#7A5C00",
    "err":       "#A01818",
    "text":      "#1A1A1A",
    "text_dim":  "#606060",
    "hex_bg":    "#FAFAFA",
    "hex_addr":  "#1A6DB5",
    "hex_data":  "#1A1A1A",
    "hex_ff":    "#C0C0C0",
    "hex_ascii": "#1B6E2E",
    "log_ts":    "#909090",
}

FU  = ("Segoe UI", 9)
FUB = ("Segoe UI", 9,  "bold")
FH  = ("Segoe UI", 10, "bold")
FM  = ("Consolas", 9)
FMS = ("Consolas", 8)


# ─────────────────────────────────────────────────────────────────────────────
# MAIN APP
# ─────────────────────────────────────────────────────────────────────────────
class App:
    def __init__(self, root: tk.Tk):
        self.root = root
        self.root.title("AM29F010 / AM29F040B Flash Programmer")
        self.root.geometry("1400x800")
        self.root.minsize(1400, 800)
        self.root.configure(bg=C["bg"])

        self.serial_port: serial.Serial | None = None
        self.worker:      SerialWorker  | None = None
        self.is_connected = False
        self.is_busy      = False
        self.current_data: bytes | None = None

        self.var_port     = tk.StringVar()
        self.var_baud     = tk.StringVar(value="115200")
        self.var_chip     = tk.StringVar(value=DEFAULT_CHIP)
        self.var_mfr_id   = tk.StringVar(value="—")
        self.var_mfr_name = tk.StringVar(value="—")
        self.var_dev_id   = tk.StringVar(value="—")
        self.var_dev_name = tk.StringVar(value="—")
        self.var_start    = tk.StringVar(value="000000")
        self.var_end      = tk.StringVar(value="07FFFF")
        self.var_verify   = tk.BooleanVar(value=True)

        self._setup_ttk()
        self._build_ui()
        self._refresh_ports()

    # ── STYLES ──────────────────────────────────────────────────────────────
    def _setup_ttk(self):
        s = ttk.Style()
        s.theme_use("clam")

        s.configure(".",              background=C["bg"],    foreground=C["text"],  font=FU)
        s.configure("TFrame",         background=C["bg"])
        s.configure("White.TFrame",   background=C["panel"])
        s.configure("TLabel",         background=C["bg"],    foreground=C["text"])
        s.configure("W.TLabel",       background=C["panel"], foreground=C["text"])
        s.configure("Dim.TLabel",     background=C["panel"], foreground=C["text_dim"])

        s.configure("TLabelframe",        background=C["panel"], bordercolor=C["border"])
        s.configure("TLabelframe.Label",  background=C["panel"], foreground=C["accent"], font=FUB)

        s.configure("TButton",        background=C["panel"], foreground=C["text"],
                    bordercolor=C["border"], font=FU, padding=(6,3), relief="flat")
        s.map("TButton",
              background=[("active", C["border"]), ("disabled", C["bg"])],
              foreground=[("disabled", C["text_dim"])])

        s.configure("Accent.TButton", background=C["accent"], foreground="white",
                    font=FUB, padding=(8,4))
        s.map("Accent.TButton",
              background=[("active", "#145591"), ("disabled", C["border"])])

        s.configure("Danger.TButton", background=C["err"], foreground="white",
                    font=FUB, padding=(8,4))
        s.map("Danger.TButton",
              background=[("active", "#7a1212"), ("disabled", C["border"])])

        s.configure("OK.TButton",     background=C["ok"], foreground="white",
                    font=FUB, padding=(8,4))
        s.map("OK.TButton",
              background=[("active", "#145522"), ("disabled", C["border"])])

        s.configure("TCombobox", fieldbackground=C["panel"], background=C["panel"],
                    foreground=C["text"])
        s.map("TCombobox", fieldbackground=[("readonly", C["panel"])])

        s.configure("TEntry",    fieldbackground=C["panel"], foreground=C["text"])

        s.configure("TProgressbar", background=C["accent"], troughcolor=C["border"],
                    bordercolor=C["border"])

        s.configure("TCheckbutton", background=C["panel"], foreground=C["text"])
        s.map("TCheckbutton",       background=[("active", C["panel"])])
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

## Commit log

2026-02-21 GUI updated, dropdown bugs fixed, help button added
2026-02-22 Schematic files added
    [amd-flash-programmer.kicad_pcb, amd-flash-programmer.kicad_sch]
2026-03-03 PCB design added to schematic folder
    [amd-flash-programmer.kicad_pcb]
2026-03-05 PCB rerouted without vias, silkscreen updated
    [amd-flash-programmer.kicad_pcb]
2026-03-23 PCB updated
    [amd-flash-programmer.kicad_pcb]
